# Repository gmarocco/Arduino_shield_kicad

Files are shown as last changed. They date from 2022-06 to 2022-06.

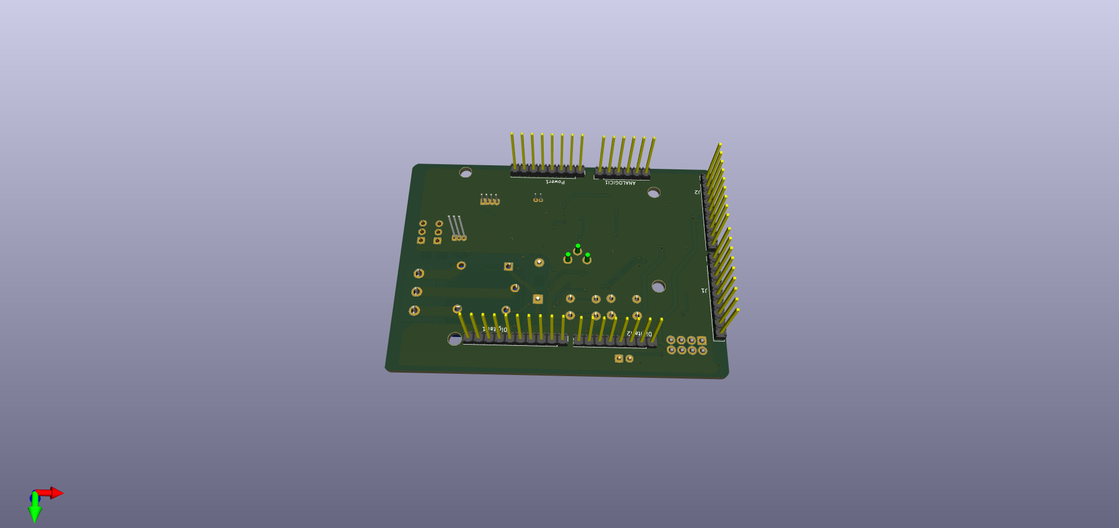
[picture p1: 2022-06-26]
documentazione Shield Arduino v2/Shield Arduino v2-1_bottom.png

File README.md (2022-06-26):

# Arduino_shield_kicad
Shield general purpose for Arduino Uno board
La scheda ospita queste sezioni
• E’ presente uno stadio che implementa un interruttore audio
• La scheda contiene un trimmer collegato a un pin analogico della scheda Arduino
• Sono presenti due pulsanti
• La scheda contiene un LED RGB da 5mm
• E’ presente un relè da 10 A
• La scheda è predisposta per ospitare il modulo Wi-Fi ESP8266
• E’ presente un regolatore lineare che genera una tensione di 3.3V con una corrente massima di 1 A
• Sono presenti due header maschio che permettono allo shield di essere collegato a una breadboard

I file di progetto sono stati realizzati con Kicad v6

English description

The board has these sections
• There is a stage that implements an audio switch
• The board contains a trimmer connected to an analog pin of the Arduino board
• There are two buttons
• The board contains a 5mm RGB LED
• There is a 10 A relay
• The card is designed to house the ESP8266 Wi-Fi module
• There is a linear regulator that generates a voltage of 3.3V with a maximum current of 1 A
• There are two male headers that allow the shield to be connected to a breadboard

The project files are made with Kicad v6

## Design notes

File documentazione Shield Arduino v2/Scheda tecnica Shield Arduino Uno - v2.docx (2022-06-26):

Documentazione Shield Arduino Uno v2

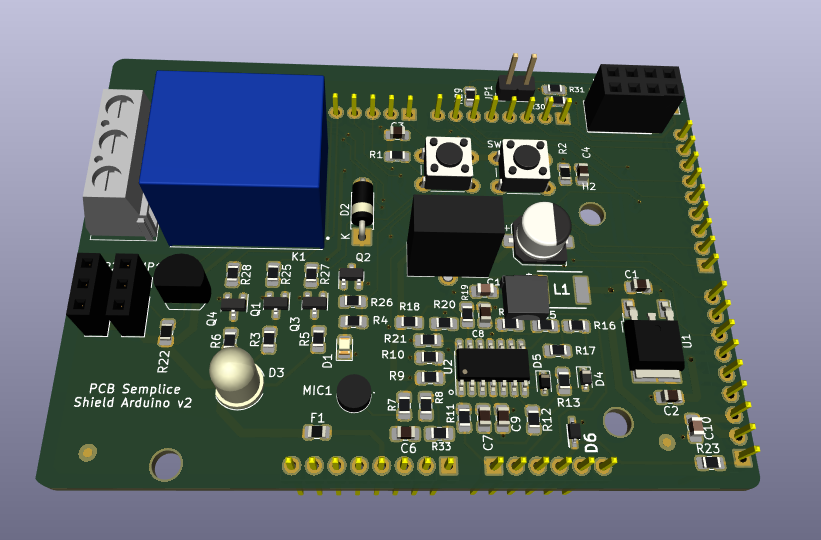
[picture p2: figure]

## Descrizione generale

La scheda ospita queste sezioni

- E’ presente uno stadio che implementa un interruttore audio
- La scheda contiene un trimmer collegato a un pin analogico della scheda Arduino
- Sono presenti due pulsanti
- La scheda contiene un LED RGB da 5mm
- E’ presente un relè da 10 A
- La scheda è predisposta per ospitare il modulo Wi-Fi ESP8266
- E’ presente un regolatore lineare che genera una tensione di 3.3V con una corrente massima di 1 A
- Sono presenti due header maschio che permettono allo shield di essere collegato a una breadboard

## Interruttore audio

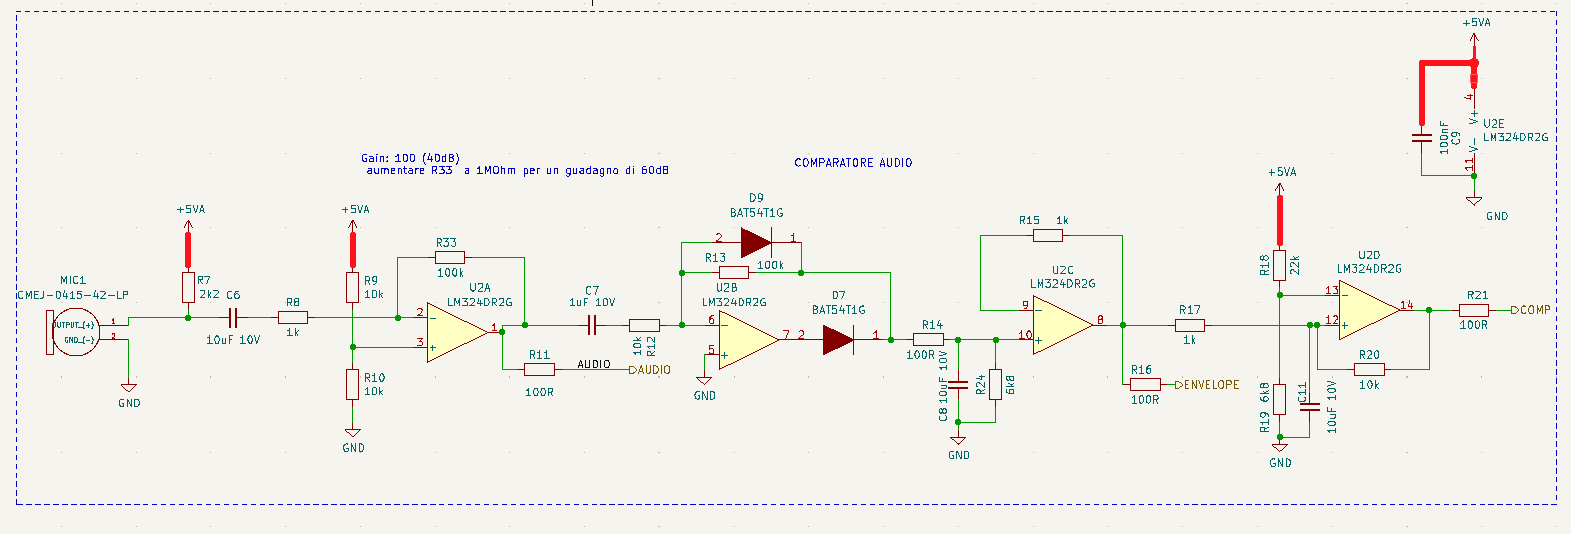
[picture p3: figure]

Lo stadio si basa sull’amplificatore operazionale a 4 canali LM324

La prima sezione (U2A) dell’operazionale realizza un amplificatore invertente. Il segnale del microfono viene amplificato e il guadagno è determinato sostanzialmente dal resistore R33

L’uscita viene inviata sia a un canale analogico della scheda Arduino Uno, sia al secondo stadio (U2B) che realizza un raddrizzatore a singola semionda (half wave rectifier).

L‘uscita del raddrizzatore viene inviata al terzo stadio (U2C) che costituisce un buffer con un filtro passa-basso.

L’uscita di quest’ultimo stadio viene inviata sia a un pin analogico della scheda Arduino Uno, sia al quarto stadio (U2D) che è un trigger di Schmitt. L’uscita (COMP) di quest’ ultimo stadio viene inviata a un pin digitale della Arduino Uno.

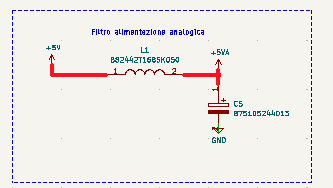
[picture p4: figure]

Per evitare commutazioni spurie, la tensione di alimentazione (+5VA) dell’operazionale è ottenuta dalla tensione +5V attraverso un filtro costituito dall’induttore L1 e dal condensatore C5

Lo sketch caricato nel microcontrollore AtMEGA328P della scheda Arduino Uno, attiva un relè quando viene pronunciato per due volte il suono “a”. Il relè viene disattivato quando viene pronunciato tre volte il suono “a”

const byte ledPin = 12;

const byte rele = 4;

const byte interruptPin = 2;

volatile byte state = LOW;

unsigned char count =0;

unsigned char ON =0;

unsigned char OFF =0;

unsigned long timeComparison = 0;

unsigned char alreadyON =0;

void setup() {

pinMode(ledPin, OUTPUT);

pinMode(interruptPin, INPUT_PULLUP);

attachInterrupt(digitalPinToInterrupt(interruptPin), checkComparator, RISING);

Serial.begin(9600);

}

void loop() {

Serial.println(count);

if (ON==1 && alreadyON==0)

{

digitalWrite(ledPin, HIGH);

digitalWrite(rele, HIGH);

alreadyON=1;

count=0;

Serial.println("ON");

}

if (OFF==1){

digitalWrite(ledPin, LOW);

digitalWrite(rele, LOW);

Serial.println("OFF");

alreadyON =0;

count=0;

OFF=0;

}

}

void checkComparator() {

count++;

switch (count){

case 1:

timeComparison=millis();

break;

case 2:

timeComparison=(millis())-timeComparison;

if (timeComparison <2000)

{

ON=1;

OFF=0;

timeComparison=millis();

}

else{

count=0;

}

break;

case 3:

timeComparison=(millis())-timeComparison;

if (timeComparison <2000)

{

ON=0;

OFF=1;

count =0;

}

else{

count=0;

}

break;

default:

count=0;

break;

}

}

## Predisposizione per collegare un modulo ESP8266

E’ possibile interfacciarsi con un modulo Wi-Fi ESP8266 montando il componente in corrispondenza del connettore J4. Orientare il modulo in modo che sia tutto all’interno dello shield.

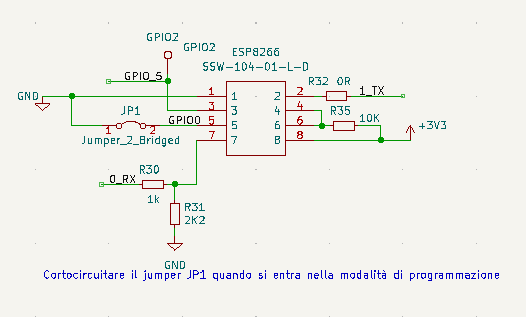
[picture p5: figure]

Prima di programmare il modulo, caricare lo sketch qui sotto nel microcontrollore ATMEGA328P della scheda Arduino Uno in modo che non si creino conflitti a livello di comunicazione seriale (pin 0 e pin 1 della scheda Arduino UNO) Lo sketch permette, inoltre di comandare il relè in base allo stato del pin GIPO5.

const int EspOutput = 5; // ESP8266 output

const int rele = 4; // the number of the LED pin

const int led= 13;

void setup() {

pinMode(EspOutput, INPUT);

pinMode(rele, OUTPUT);

pinMode(led, OUTPUT);

// put your setup code here, to run once:

}

void loop() {

if (digitalRead(EspOutput))

{

delay(500);

if (digitalRead(EspOutput))

{

digitalWrite(rele,HIGH);

digitalWrite(led,HIGH);

}

else

{

digitalWrite(led,LOW);

digitalWrite(rele,LOW);

}

}

}

La resistenza R29 permette di selezionare se collegare un’uscita digitale del modulo al pin GPIO5 della scheda Arduino Uno. In questo caso il pin della scheda Arduino dovrà essere configurato come ingresso.

Per l’impostazione del modulo, fare riferimento al video ( E’ in inglese) https://www.youtube.com/watch?v=AvSCAxbqvvE.

Prima di programmare il modulo Wi-Fi, togliere alimentazione allo shield e inserire un jumper in corrispondenza del connettore JP1. A questo punto fornire nuovamente l’alimentazione e programmare il microcontrollore usando lo sketch “Blynk_NodeMCU_ESP8266” selezionando come board “Generic ESP8266 module”. E’ fondamentale sostituire i parametri BLYNK_TEMPLATE_ID e BLYNK_DEVICE_NAME con i valori forniti quando si crea l’applicazione attraverso il portale https://blynk.cloud/

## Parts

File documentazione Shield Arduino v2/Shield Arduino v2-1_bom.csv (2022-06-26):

Source: | C:\Users\pc\Documents\progetto PCB semplice\3° versione Kicad\live\Shield Arduino v2-1\Shield Arduino v2-1.kicad_sch
Date: | 26/06/2022 13:20:24
Tool: | Eeschema (6.0.6)
Generator: | C:\Program Files\KiCad\6.0\bin\scripting\plugins/bom_csv_grouped_by_value.py
Component Count: | 84
Individual Components:
Item | Qty | Reference(s) | Value | LibPart | Footprint | Datasheet | Description | Height | MANUFACTURER | Manufacturer_Name | Manufacturer_Part_Number | Mouser Part Number | Mouser Price/Stock | STANDARD
 |  | ANALOGICI1 | Conn_01x06 | Connector_Generic:Conn_01x06 | Connector_PinHeader_2.54mm:PinHeader_1x06_P2.54mm_Vertical | ~
 |  | C1 | 10uF 10V | Device:C_Small | Capacitor_SMD:C_0805_2012Metric_Pad1.15x1.40mm_HandSolder | ~
 |  | C2 | 10uF 10V | Device:C_Small | Capacitor_SMD:C_0805_2012Metric_Pad1.15x1.40mm_HandSolder | ~
 |  | C3 | 100nF | Device:C_Small | Capacitor_SMD:C_0805_2012Metric_Pad1.15x1.40mm_HandSolder | ~
 |  | C4 | 100nF | Device:C_Small | Capacitor_SMD:C_0805_2012Metric_Pad1.15x1.40mm_HandSolder | ~
 |  | C5 | 865080253012 470uF 10V | SamacSys_lib:875105244013 | Capacitor_SMD:CP_Elec_8x6.2 | https://www.we-online.com/catalog/datasheet/875105244013.pdf | Wurth Elektronik 470uF Polymer Capacitor 10V dc Surface Mount -865080253012 | 5.8 |  | Wurth Elektronik | 875105244013 | 710-875105244013 | https://www.mouser.co.uk/ProductDetail/Wurth-Elektronik/875105244013?qs=0KOYDY2FL29vol3nJUb9dw%3D%3D
 |  | C6 | 10uF 10V | Device:C_Small | Capacitor_SMD:C_0805_2012Metric_Pad1.15x1.40mm_HandSolder | ~
 |  | C7 | 1uF 10V | Device:C_Small | Capacitor_SMD:C_0805_2012Metric_Pad1.15x1.40mm_HandSolder | ~
 |  | C8 | 10uF 10V | Device:C_Small | Capacitor_SMD:C_0805_2012Metric_Pad1.15x1.40mm_HandSolder | ~
 |  | C9 | 100nF | Device:C_Small | Capacitor_SMD:C_0805_2012Metric_Pad1.15x1.40mm_HandSolder | ~
 |  | C10 | 100nF | Device:C_Small | Capacitor_SMD:C_0805_2012Metric_Pad1.18x1.45mm_HandSolder | ~
 |  | C11 | 10uF 10V | Device:C_Small | Capacitor_SMD:C_0805_2012Metric_Pad1.18x1.45mm_HandSolder | ~
 |  | D1 | LED | Device:LED | LED_SMD:LED_0805_2012Metric | ~
 |  | D2 | 1N4001 | Diode:1N4001 | Diode_THT:D_DO-41_SOD81_P10.16mm_Horizontal | http://www.vishay.com/docs/88503/1n4001.pdf
 |  | D3 | LED_ABRG | Device:LED_ABRG | LED_THT:LED_D5.0mm-4_RGB | ~
 |  | D6 | AQ3530-01FTG | SamacSys_lib:AQ3530-01FTG | SOD2613X100N | https://www.littelfuse.com/~/media/electronics/datasheets/tvs_diode_arrays/littelfuse_tvs_diode_array_aq3530-01ftg_datasheet.pdf.pdf | 0.3pF 22kV unidirectional TVS diode | 1 |  | LITTELFUSE | AQ3530-01FTG | 576-AQ3530-01FTG | https://www.mouser.co.uk/ProductDetail/Littelfuse/AQ3530-01FTG?qs=yqaQSyyJnNi2YblDWyDyIw%3D%3D
 |  | D7 | BAT54T1G | LIBRARY LOADER_AUTO:BAT54T1G | SOD3716X135N | http://www.onsemi.com/pub/Collateral/BAT54T1-D.PDF |  | 1.35 |  | onsemi | BAT54T1G | 863-BAT54T1G | https://www.mouser.co.uk/ProductDetail/onsemi/BAT54T1G?qs=vLkC5FC1VN9XK%252B%252BtdP3lYw%3D%3D
 |  | D9 | BAT54T1G | LIBRARY LOADER_AUTO:BAT54T1G | SOD3716X135N | http://www.onsemi.com/pub/Collateral/BAT54T1-D.PDF |  | 1.35 |  | onsemi | BAT54T1G | 863-BAT54T1G | https://www.mouser.co.uk/ProductDetail/onsemi/BAT54T1G?qs=vLkC5FC1VN9XK%252B%252BtdP3lYw%3D%3D
 |  | Digitali1 | Conn_01x10 | Connector_Generic:Conn_01x10 | Connector_PinHeader_2.54mm:PinHeader_1x10_P2.54mm_Vertical | ~
 |  | Digitali2 | Conn_01x08 | Connector_Generic:Conn_01x08 | Connector_PinHeader_2.54mm:PinHeader_1x08_P2.54mm_Vertical | ~
 |  | ESP8266 | SSW-104-01-L-D | SamacSys_Parts:SSW-104-01-L-D | RHDR8W79P254_2X4_1067X495X851P | http://suddendocs.samtec.com/prints/ssw-1xx-xx-xxx-x-xx-xxx-xx-mkt.pdf | 8 Position, .100&quot; Tiger Buy&trade; Socket Strip | 8.51 |  | SAMTEC | SSW-104-01-L-D | 200-SSW10401LD | https://www.mouser.co.uk/ProductDetail/Samtec/SSW-104-01-L-D/?qs=%252BZP6%2F%252BtExtBqD4BX7Y8soA%3D%3D
 |  | F1 | 0ZCH0150FF2E | Device:Polyfuse | Fuse:Fuse_1210_3225Metric_Pad1.42x2.65mm_HandSolder | ~
 |  | FID1 | Fiducial | Mechanical:Fiducial | Fiducial:Fiducial_1mm_Mask2mm | ~
 |  | FID2 | Fiducial | Mechanical:Fiducial | Fiducial:Fiducial_1mm_Mask2mm | ~
 |  | FID3 | Fiducial | Mechanical:Fiducial | Fiducial:Fiducial_1mm_Mask2mm | ~
 |  | GPIO2 | GPIO2 | Connector:TestPoint | TestPoint:TestPoint_Pad_1.5x1.5mm | ~
 |  | H1 | MountingHole | Mechanical:MountingHole | MountingHole:MountingHole_3.2mm_M3 | ~
 |  | H2 | MountingHole | Mechanical:MountingHole | MountingHole:MountingHole_3.2mm_M3 | ~
 |  | H3 | MountingHole | Mechanical:MountingHole | MountingHole:MountingHole_3.2mm_M3 | ~
 |  | H4 | MountingHole | Mechanical:MountingHole | MountingHole:MountingHole_3.2mm_M3 | ~
 |  | J1 | Conn_01x09 | Connector_Generic:Conn_01x09 | Connector_PinHeader_2.54mm:PinHeader_1x09_P2.54mm_Vertical | ~
 |  | J2 | Conn_01x09 | Connector_Generic:Conn_01x09 | Connector_PinHeader_2.54mm:PinHeader_1x09_P2.54mm_Vertical | ~
 |  | J3 | TERMINAL BLOCK 3 POSIZIONI | SamacSys_Parts:282837-3 | LibraryLoaderAuto:TB00950803BE |  | Fixed Terminal Blocks 5.08MM PCB MOUNT 3P | 10.3 |  | TE Connectivity | 282837-3 | 571-2828373 | https://www.mouser.co.uk/ProductDetail/TE-Connectivity/282837-3?qs=A%252Bip%252BNCYi6PMRxtBYEOSrQ%3D%3D
 |  | JP1 | Jumper_2_Bridged | Jumper:Jumper_2_Bridged | Connector_PinHeader_2.54mm:PinHeader_1x02_P2.54mm_Vertical | ~
 |  | K1 | SRD-05VDC-SL-C | SRD-05VDC-SL-C:SRD-05VDC-SL-C | RELAY_SRD-05VDC-SL-C |  |  |  | SONGLE RELAY |  |  |  |  | IPC-7251
 |  | L1 | B82442T1685K050 | SamacSys_lib:B82442T1685K050 | INDPM5850X530N | https://componentsearchengine.com/Datasheets/1/B82442T1685K050.pdf | SMD / SMT Inductors (Coils), L=6800uH, 5.6mm x 5.0mm [EIA 2220] | 5.3 |  | TDK | B82442T1685K050 | 871-B82442T1685K050 | http://www.mouser.com/Search/ProductDetail.aspx?qs=x3Z3Taiycdsue7u9bW7ngg%3d%3d
 |  | MIC1 | CMEJ-0415-42-LP | LibraryLoader:CMEJ-0415-42-LP | LibraryLoaderAuto:CMEJ041542LP | https://componentsearchengine.com/Datasheets/1/CMEJ-0415-42-LP.pdf | Microphones microphone, 4 mm, electret condenser, omnidirectional, Long Pin, 2 Vdc, 42 dB sensitivity | 2 |  | CUI Inc. | CMEJ-0415-42-LP | 490-CMEJ-0415-42-LP | https://www.mouser.co.uk/ProductDetail/CUI-Devices/CMEJ-0415-42-LP?qs=PzGy0jfpSMvQKgQIwTg7Mg%3D%3D
 |  | Power1 | Conn_01x08 | Connector_Generic:Conn_01x08 | Connector_PinHeader_2.54mm:PinHeader_1x08_P2.54mm_Vertical | ~
 |  | Q1 | BC848 | Transistor_BJT:BC848 | Package_TO_SOT_SMD:SOT-23 | http://www.infineon.com/dgdl/Infineon-BC847SERIES_BC848SERIES_BC849SERIES_BC850SERIES-DS-v01_01-en.pdf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
 |  | Q2 | DMN3404L | Transistor_FET:DMN3404L | Package_TO_SOT_SMD:SOT-23 | http://www.diodes.com/assets/Datasheets/ds31787.pdf
 |  | Q3 | BC848 | Transistor_BJT:BC848 | Package_TO_SOT_SMD:SOT-23 | http://www.infineon.com/dgdl/Infineon-BC847SERIES_BC848SERIES_BC849SERIES_BC850SERIES-DS-v01_01-en.pdf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
 |  | Q4 | BC848 | Transistor_BJT:BC848 | Package_TO_SOT_SMD:SOT-23 | http://www.infineon.com/dgdl/Infineon-BC847SERIES_BC848SERIES_BC849SERIES_BC850SERIES-DS-v01_01-en.pdf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
 |  | R1 | 10K | Device:R_Small | Resistor_SMD:R_0805_2012Metric_Pad1.15x1.40mm_HandSolder | ~
 |  | R2 | 10K | Device:R_Small | Resistor_SMD:R_0805_2012Metric_Pad1.15x1.40mm_HandSolder | ~
 |  | R3 | 220R | Device:R_Small | Resistor_SMD:R_0805_2012Metric_Pad1.15x1.40mm_HandSolder | ~
 |  | R4 | 1K | Device:R_Small | Resistor_SMD:R_0805_2012Metric_Pad1.15x1.40mm_HandSolder | ~
 |  | R5 | 220R | Device:R_Small | Resistor_SMD:R_0805_2012Metric_Pad1.15x1.40mm_HandSolder | ~
 |  | R6 | 220R | Device:R_Small | Resistor_SMD:R_0805_2012Metric_Pad1.15x1.40mm_HandSolder | ~
 |  | R7 | 2k2 | Device:R | Resistor_SMD:R_0805_2012Metric_Pad1.15x1.40mm_HandSolder | ~
 |  | R8 | 1k | Device:R | Resistor_SMD:R_0805_2012Metric_Pad1.15x1.40mm_HandSolder | ~
 |  | R9 | 10k | Device:R | Resistor_SMD:R_0805_2012Metric_Pad1.15x1.40mm_HandSolder | ~
 |  | R10 | 10k | Device:R | Resistor_SMD:R_0805_2012Metric_Pad1.15x1.40mm_HandSolder | ~
 |  | R11 | 100R | Device:R | Resistor_SMD:R_0805_2012Metric_Pad1.15x1.40mm_HandSolder | ~
 |  | R12 | 10k | Device:R | Resistor_SMD:R_0805_2012Metric_Pad1.15x1.40mm_HandSolder | ~
 |  | R13 | 100k | Device:R | Resistor_SMD:R_0805_2012Metric_Pad1.15x1.40mm_HandSolder | ~
 |  | R14 | 100R | Device:R | Resistor_SMD:R_0805_2012Metric_Pad1.15x1.40mm_HandSolder | ~
 |  | R15 | 1k | Device:R | Resistor_SMD:R_0805_2012Metric_Pad1.15x1.40mm_HandSolder | ~
 |  | R16 | 100R | Device:R | Resistor_SMD:R_0805_2012Metric_Pad1.15x1.40mm_HandSolder | ~
 |  | R17 | 1k | Device:R | Resistor_SMD:R_0805_2012Metric_Pad1.15x1.40mm_HandSolder | ~
 |  | R18 | 22k | Device:R | Resistor_SMD:R_0805_2012Metric_Pad1.15x1.40mm_HandSolder | ~
 |  | R19 | 6k8 | Device:R | Resistor_SMD:R_0805_2012Metric_Pad1.15x1.40mm_HandSolder | ~
 |  | R20 | 10k | Device:R | Resistor_SMD:R_0805_2012Metric_Pad1.15x1.40mm_HandSolder | ~
 |  | R21 | 100R | Device:R | Resistor_SMD:R_0805_2012Metric_Pad1.15x1.40mm_HandSolder | ~
 |  | R22 | 10k | Device:R_Small | Resistor_SMD:R_0805_2012Metric_Pad1.15x1.40mm_HandSolder | ~
 |  | R23 | 100R | Device:R_Small | Resistor_SMD:R_0805_2012Metric_Pad1.20x1.40mm_HandSolder | ~
 |  | R24 | 6k8 | Device:R | Resistor_SMD:R_0805_2012Metric_Pad1.20x1.40mm_HandSolder | ~
 |  | R26 | 3k3 | Device:R_Small | Resistor_SMD:R_0805_2012Metric_Pad1.20x1.40mm_HandSolder | ~
 |  | R27 | 1K | Device:R_Small | Resistor_SMD:R_0805_2012Metric_Pad1.20x1.40mm_HandSolder | ~
 |  | R28 | 1K | Device:R_Small | Resistor_SMD:R_0805_2012Metric_Pad1.20x1.40mm_HandSolder | ~
 |  | R29 | 0R | Device:R_Small | Resistor_SMD:R_0805_2012Metric_Pad1.20x1.40mm_HandSolder | ~
 |  | R30 | 1k | Device:R_Small | Resistor_SMD:R_0805_2012Metric_Pad1.20x1.40mm_HandSolder | ~
 |  | R31 | 2K2 | Device:R_Small | Resistor_SMD:R_0805_2012Metric_Pad1.20x1.40mm_HandSolder | ~
 |  | R32 | 0R | Device:R_Small | Resistor_SMD:R_0805_2012Metric_Pad1.20x1.40mm_HandSolder | ~
 |  | R33 | 100k | Device:R | Resistor_SMD:R_0805_2012Metric_Pad1.20x1.40mm_HandSolder | ~
 |  | R34 | 220k | Device:R_Small | Resistor_SMD:R_0805_2012Metric_Pad1.20x1.40mm_HandSolder | ~
 |  | R35 | 10K | Device:R_Small | Resistor_SMD:R_0805_2012Metric_Pad1.20x1.40mm_HandSolder | ~
 |  | SW1 | SW_Push | Switch:SW_Push | Button_Switch_THT:SW_PUSH_6mm_H4.3mm | ~
 |  | SW2 | SW_Push | Switch:SW_Push | Button_Switch_THT:SW_PUSH_6mm_H4.3mm | ~
 |  | TEMP1 | Conn_01x03 | Connector_Generic:Conn_01x03 | Connector_PinSocket_2.54mm:PinSocket_1x03_P2.54mm_Vertical | ~
 |  | TEMP2 | Conn_01x03 | Connector_Generic:Conn_01x03 | Connector_PinSocket_2.54mm:PinSocket_1x03_P2.54mm_Vertical | ~
 |  | U1 | NCP1117-3.3 | Regulator_Linear:NCP1117-3.3_TO252 | Package_TO_SOT_SMD:TO-252-2 | http://www.onsemi.com/pub_link/Collateral/NCP1117-D.PDF
 |  | U2 | LM324DR2G | Amplifier_Operational:LM324 | Package_SO:SOIC-14_3.9x8.7mm_P1.27mm | http://www.ti.com/lit/ds/symlink/lm2902-n.pdf
 |  | U3 | DS18B20 | Sensor_Temperature:DS18B20 | Package_TO_SOT_THT:TO-92_Inline | http://datasheets.maximintegrated.com/en/ds/DS18B20.pdf
 |  | VR1 | PT10MH01-103A2020-S | SamacSys_lib:PT10MH01-103A2020-S | LibraryLoaderAuto:PT10MH01103A2020S | https://www.piher.net/pdf/12-PT10v03.pdf | TRIMMER, 10K, 0.15W, 1TURN; Track Resistance:10kohm; No. of Turns:1Turns; Potentiometer Mounting:Through Hole; Product Range:PT-10 Series; Power Rating:150mW; Resistance Tolerance:+/- 20%; Temperature Coefficient:+/- 300ppm/C; RoHS Compliant: Yes | 12.3 |  | PIHER | PT10MH01-103A2020-S | 531-PT10MH-10K-S | https://www.mouser.co.uk/ProductDetail/Amphenol-Piher/PT10MH01-103A2020-S?qs=pCZPOPZMYPhUHYDrMqsu3w%3D%3D
Collated Components:
Item | Qty | Reference(s) | Value | LibPart | Footprint | Datasheet | Description | Height | MANUFACTURER | Manufacturer_Name | Manufacturer_Part_Number | Mouser Part Number | Mouser Price/Stock | STANDARD
1 | 1 | ANALOGICI1 | Conn_01x06 | Connector_Generic:Conn_01x06 | Connector_PinHeader_2.54mm:PinHeader_1x06_P2.54mm_Vertical | ~
2 | 4 | C1, C2, C6, C8 | 10uF 10V | Device:C_Small | Capacitor_SMD:C_0805_2012Metric_Pad1.15x1.40mm_HandSolder | ~
3 | 3 | C3, C4, C9 | 100nF | Device:C_Small | Capacitor_SMD:C_0805_2012Metric_Pad1.15x1.40mm_HandSolder | ~
4 | 1 | C5 | 865080253012 470uF 10V | SamacSys_lib:875105244013 | Capacitor_SMD:CP_Elec_8x6.2 | https://www.we-online.com/catalog/datasheet/875105244013.pdf | Wurth Elektronik 470uF Polymer Capacitor 10V dc Surface Mount -865080253012 | 5.8 |  | Wurth Elektronik | 875105244013 | 710-875105244013 | https://www.mouser.co.uk/ProductDetail/Wurth-Elektronik/875105244013?qs=0KOYDY2FL29vol3nJUb9dw%3D%3D
5 | 1 | C7 | 1uF 10V | Device:C_Small | Capacitor_SMD:C_0805_2012Metric_Pad1.15x1.40mm_HandSolder | ~
6 | 1 | C10 | 100nF | Device:C_Small | Capacitor_SMD:C_0805_2012Metric_Pad1.18x1.45mm_HandSolder | ~
7 | 1 | C11 | 10uF 10V | Device:C_Small | Capacitor_SMD:C_0805_2012Metric_Pad1.18x1.45mm_HandSolder | ~
8 | 1 | D1 | LED | Device:LED | LED_SMD:LED_0805_2012Metric | ~
9 | 1 | D2 | 1N4001 | Diode:1N4001 | Diode_THT:D_DO-41_SOD81_P10.16mm_Horizontal | http://www.vishay.com/docs/88503/1n4001.pdf
10 | 1 | D3 | LED_ABRG | Device:LED_ABRG | LED_THT:LED_D5.0mm-4_RGB | ~
11 | 1 | D6 | AQ3530-01FTG | SamacSys_lib:AQ3530-01FTG | SOD2613X100N | https://www.littelfuse.com/~/media/electronics/datasheets/tvs_diode_arrays/littelfuse_tvs_diode_array_aq3530-01ftg_datasheet.pdf.pdf | 0.3pF 22kV unidirectional TVS diode | 1 |  | LITTELFUSE | AQ3530-01FTG | 576-AQ3530-01FTG | https://www.mouser.co.uk/ProductDetail/Littelfuse/AQ3530-01FTG?qs=yqaQSyyJnNi2YblDWyDyIw%3D%3D
12 | 2 | D7, D9 | BAT54T1G | LIBRARY LOADER_AUTO:BAT54T1G | SOD3716X135N | http://www.onsemi.com/pub/Collateral/BAT54T1-D.PDF |  | 1.35 |  | onsemi | BAT54T1G | 863-BAT54T1G | https://www.mouser.co.uk/ProductDetail/onsemi/BAT54T1G?qs=vLkC5FC1VN9XK%252B%252BtdP3lYw%3D%3D
13 | 1 | Digitali1 | Conn_01x10 | Connector_Generic:Conn_01x10 | Connector_PinHeader_2.54mm:PinHeader_1x10_P2.54mm_Vertical | ~
14 | 2 | Digitali2, Power1 | Conn_01x08 | Connector_Generic:Conn_01x08 | Connector_PinHeader_2.54mm:PinHeader_1x08_P2.54mm_Vertical | ~
15 | 1 | ESP8266 | SSW-104-01-L-D | SamacSys_Parts:SSW-104-01-L-D | RHDR8W79P254_2X4_1067X495X851P | http://suddendocs.samtec.com/prints/ssw-1xx-xx-xxx-x-xx-xxx-xx-mkt.pdf | 8 Position, .100&quot; Tiger Buy&trade; Socket Strip | 8.51 |  | SAMTEC | SSW-104-01-L-D | 200-SSW10401LD | https://www.mouser.co.uk/ProductDetail/Samtec/SSW-104-01-L-D/?qs=%252BZP6%2F%252BtExtBqD4BX7Y8soA%3D%3D
16 | 1 | F1 | 0ZCH0150FF2E | Device:Polyfuse | Fuse:Fuse_1210_3225Metric_Pad1.42x2.65mm_HandSolder | ~
17 | 3 | FID1, FID2, FID3 | Fiducial | Mechanical:Fiducial | Fiducial:Fiducial_1mm_Mask2mm | ~
18 | 1 | GPIO2 | GPIO2 | Connector:TestPoint | TestPoint:TestPoint_Pad_1.5x1.5mm | ~
19 | 4 | H1, H2, H3, H4 | MountingHole | Mechanical:MountingHole | MountingHole:MountingHole_3.2mm_M3 | ~
20 | 2 | J1, J2 | Conn_01x09 | Connector_Generic:Conn_01x09 | Connector_PinHeader_2.54mm:PinHeader_1x09_P2.54mm_Vertical | ~
21 | 1 | J3 | TERMINAL BLOCK 3 POSIZIONI | SamacSys_Parts:282837-3 | LibraryLoaderAuto:TB00950803BE |  | Fixed Terminal Blocks 5.08MM PCB MOUNT 3P | 10.3 |  | TE Connectivity | 282837-3 | 571-2828373 | https://www.mouser.co.uk/ProductDetail/TE-Connectivity/282837-3?qs=A%252Bip%252BNCYi6PMRxtBYEOSrQ%3D%3D
22 | 1 | JP1 | Jumper_2_Bridged | Jumper:Jumper_2_Bridged | Connector_PinHeader_2.54mm:PinHeader_1x02_P2.54mm_Vertical | ~
23 | 1 | K1 | SRD-05VDC-SL-C | SRD-05VDC-SL-C:SRD-05VDC-SL-C | RELAY_SRD-05VDC-SL-C |  |  |  | SONGLE RELAY |  |  |  |  | IPC-7251
24 | 1 | L1 | B82442T1685K050 | SamacSys_lib:B82442T1685K050 | INDPM5850X530N | https://componentsearchengine.com/Datasheets/1/B82442T1685K050.pdf | SMD / SMT Inductors (Coils), L=6800uH, 5.6mm x 5.0mm [EIA 2220] | 5.3 |  | TDK | B82442T1685K050 | 871-B82442T1685K050 | http://www.mouser.com/Search/ProductDetail.aspx?qs=x3Z3Taiycdsue7u9bW7ngg%3d%3d
25 | 1 | MIC1 | CMEJ-0415-42-LP | LibraryLoader:CMEJ-0415-42-LP | LibraryLoaderAuto:CMEJ041542LP | https://componentsearchengine.com/Datasheets/1/CMEJ-0415-42-LP.pdf | Microphones microphone, 4 mm, electret condenser, omnidirectional, Long Pin, 2 Vdc, 42 dB sensitivity | 2 |  | CUI Inc. | CMEJ-0415-42-LP | 490-CMEJ-0415-42-LP | https://www.mouser.co.uk/ProductDetail/CUI-Devices/CMEJ-0415-42-LP?qs=PzGy0jfpSMvQKgQIwTg7Mg%3D%3D
26 | 3 | Q1, Q3, Q4 | BC848 | Transistor_BJT:BC848 | Package_TO_SOT_SMD:SOT-23 | http://www.infineon.com/dgdl/Infineon-BC847SERIES_BC848SERIES_BC849SERIES_BC850SERIES-DS-v01_01-en.pdf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
27 | 1 | Q2 | DMN3404L | Transistor_FET:DMN3404L | Package_TO_SOT_SMD:SOT-23 | http://www.diodes.com/assets/Datasheets/ds31787.pdf
28 | 2 | R1, R2 | 10K | Device:R_Small | Resistor_SMD:R_0805_2012Metric_Pad1.15x1.40mm_HandSolder | ~
29 | 3 | R3, R5, R6 | 220R | Device:R_Small | Resistor_SMD:R_0805_2012Metric_Pad1.15x1.40mm_HandSolder | ~
30 | 1 | R4 | 1K | Device:R_Small | Resistor_SMD:R_0805_2012Metric_Pad1.15x1.40mm_HandSolder | ~
31 | 1 | R7 | 2k2 | Device:R | Resistor_SMD:R_0805_2012Metric_Pad1.15x1.40mm_HandSolder | ~
32 | 3 | R8, R15, R17 | 1k | Device:R | Resistor_SMD:R_0805_2012Metric_Pad1.15x1.40mm_HandSolder | ~
33 | 4 | R9, R10, R12, R20 | 10k | Device:R | Resistor_SMD:R_0805_2012Metric_Pad1.15x1.40mm_HandSolder | ~
34 | 4 | R11, R14, R16, R21 | 100R | Device:R | Resistor_SMD:R_0805_2012Metric_Pad1.15x1.40mm_HandSolder | ~
35 | 1 | R13 | 100k | Device:R | Resistor_SMD:R_0805_2012Metric_Pad1.15x1.40mm_HandSolder | ~
36 | 1 | R18 | 22k | Device:R | Resistor_SMD:R_0805_2012Metric_Pad1.15x1.40mm_HandSolder | ~
37 | 1 | R19 | 6k8 | Device:R | Resistor_SMD:R_0805_2012Metric_Pad1.15x1.40mm_HandSolder | ~
38 | 1 | R22 | 10k | Device:R_Small | Resistor_SMD:R_0805_2012Metric_Pad1.15x1.40mm_HandSolder | ~
39 | 1 | R23 | 100R | Device:R_Small | Resistor_SMD:R_0805_2012Metric_Pad1.20x1.40mm_HandSolder | ~
40 | 1 | R24 | 6k8 | Device:R | Resistor_SMD:R_0805_2012Metric_Pad1.20x1.40mm_HandSolder | ~
41 | 1 | R26 | 3k3 | Device:R_Small | Resistor_SMD:R_0805_2012Metric_Pad1.20x1.40mm_HandSolder | ~
42 | 2 | R27, R28 | 1K | Device:R_Small | Resistor_SMD:R_0805_2012Metric_Pad1.20x1.40mm_HandSolder | ~
43 | 2 | R29, R32 | 0R | Device:R_Small | Resistor_SMD:R_0805_2012Metric_Pad1.20x1.40mm_HandSolder | ~
44 | 1 | R30 | 1k | Device:R_Small | Resistor_SMD:R_0805_2012Metric_Pad1.20x1.40mm_HandSolder | ~
45 | 1 | R31 | 2K2 | Device:R_Small | Resistor_SMD:R_0805_2012Metric_Pad1.20x1.40mm_HandSolder | ~
46 | 1 | R33 | 100k | Device:R | Resistor_SMD:R_0805_2012Metric_Pad1.20x1.40mm_HandSolder | ~
47 | 1 | R34 | 220k | Device:R_Small | Resistor_SMD:R_0805_2012Metric_Pad1.20x1.40mm_HandSolder | ~
48 | 1 | R35 | 10K | Device:R_Small | Resistor_SMD:R_0805_2012Metric_Pad1.20x1.40mm_HandSolder | ~
49 | 2 | SW1, SW2 | SW_Push | Switch:SW_Push | Button_Switch_THT:SW_PUSH_6mm_H4.3mm | ~
50 | 2 | TEMP1, TEMP2 | Conn_01x03 | Connector_Generic:Conn_01x03 | Connector_PinSocket_2.54mm:PinSocket_1x03_P2.54mm_Vertical | ~
51 | 1 | U1 | NCP1117-3.3 | Regulator_Linear:NCP1117-3.3_TO252 | Package_TO_SOT_SMD:TO-252-2 | http://www.onsemi.com/pub_link/Collateral/NCP1117-D.PDF
52 | 1 | U2 | LM324DR2G | Amplifier_Operational:LM324 | Package_SO:SOIC-14_3.9x8.7mm_P1.27mm | http://www.ti.com/lit/ds/symlink/lm2902-n.pdf
53 | 1 | U3 | DS18B20 | Sensor_Temperature:DS18B20 | Package_TO_SOT_THT:TO-92_Inline | http://datasheets.maximintegrated.com/en/ds/DS18B20.pdf
54 | 1 | VR1 | PT10MH01-103A2020-S | SamacSys_lib:PT10MH01-103A2020-S | LibraryLoaderAuto:PT10MH01103A2020S | https://www.piher.net/pdf/12-PT10v03.pdf | TRIMMER, 10K, 0.15W, 1TURN; Track Resistance:10kohm; No. of Turns:1Turns; Potentiometer Mounting:Through Hole; Product Range:PT-10 Series; Power Rating:150mW; Resistance Tolerance:+/- 20%; Temperature Coefficient:+/- 300ppm/C; RoHS Compliant: Yes | 12.3 |  | PIHER | PT10MH01-103A2020-S | 531-PT10MH-10K-S | https://www.mouser.co.uk/ProductDetail/Amphenol-Piher/PT10MH01-103A2020-S?qs=pCZPOPZMYPhUHYDrMqsu3w%3D%3D

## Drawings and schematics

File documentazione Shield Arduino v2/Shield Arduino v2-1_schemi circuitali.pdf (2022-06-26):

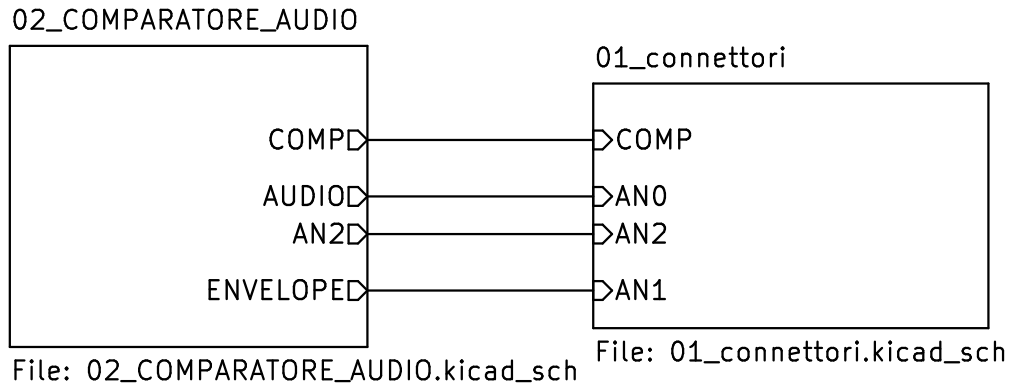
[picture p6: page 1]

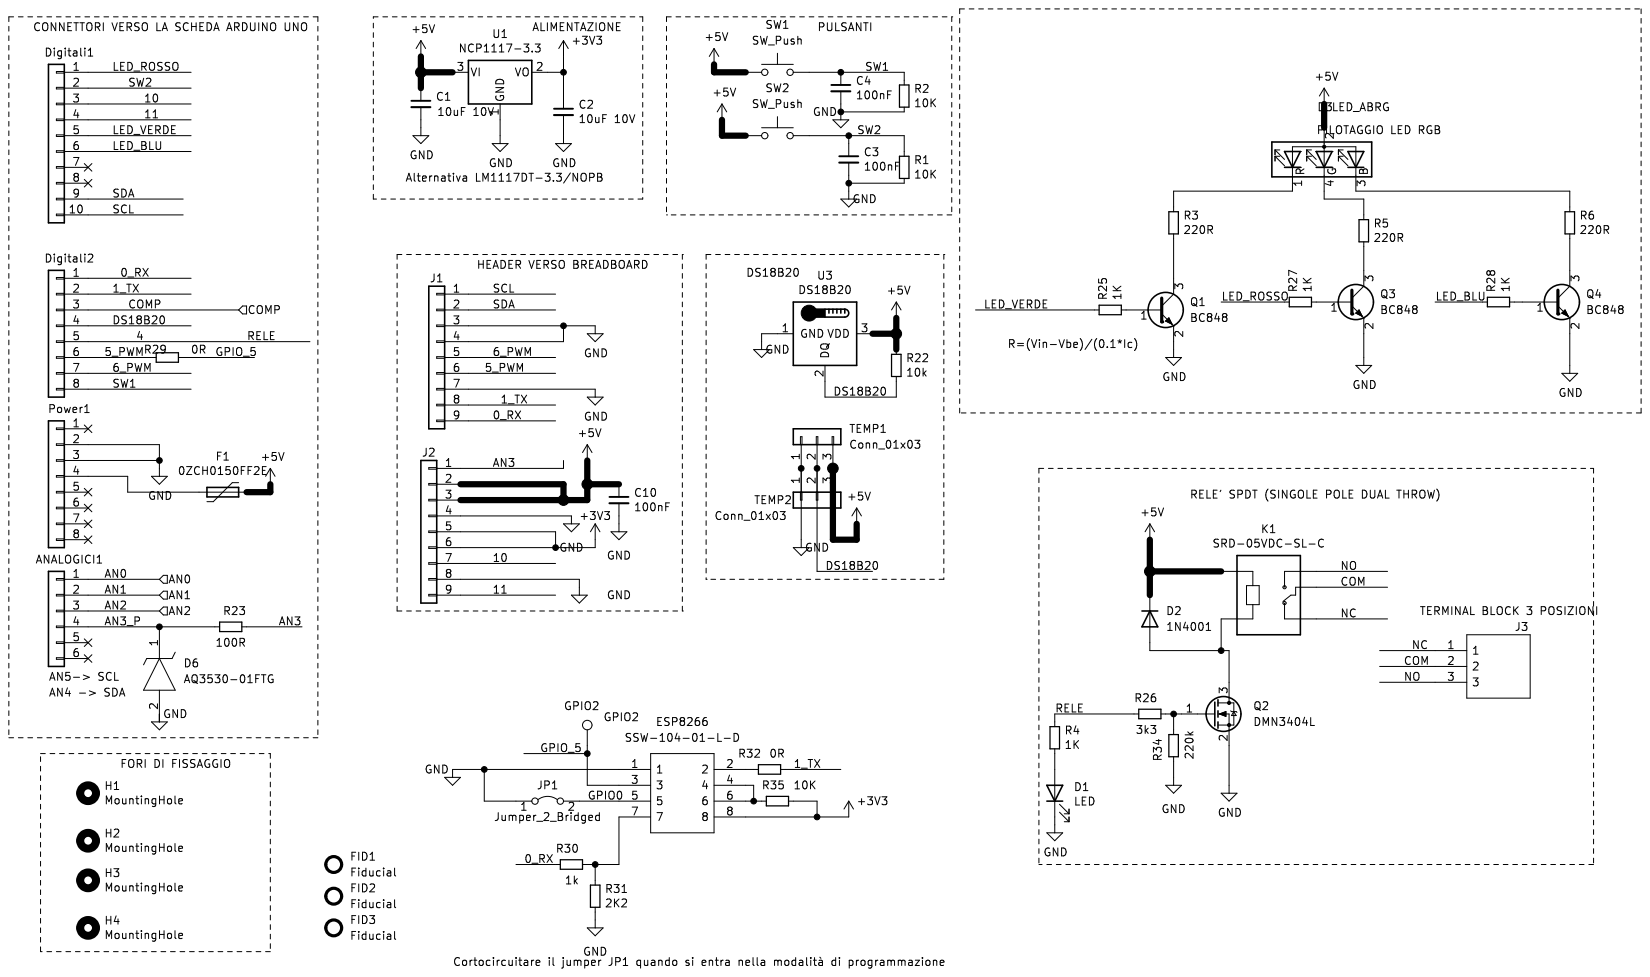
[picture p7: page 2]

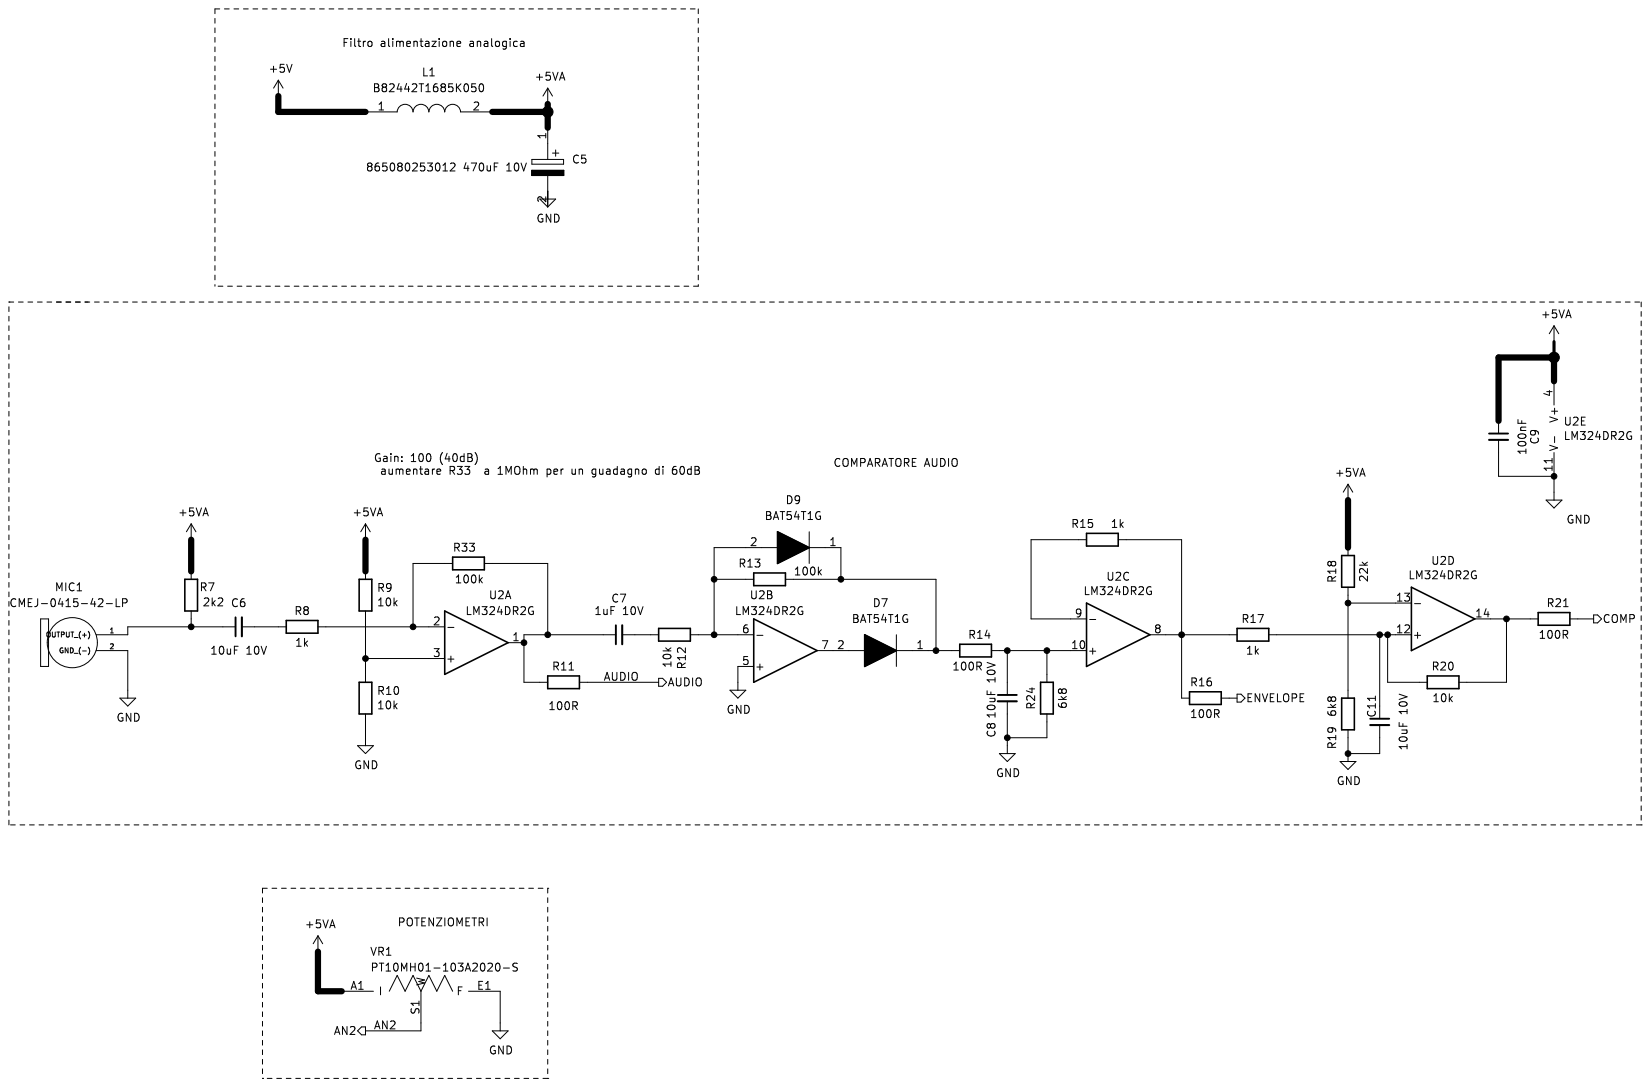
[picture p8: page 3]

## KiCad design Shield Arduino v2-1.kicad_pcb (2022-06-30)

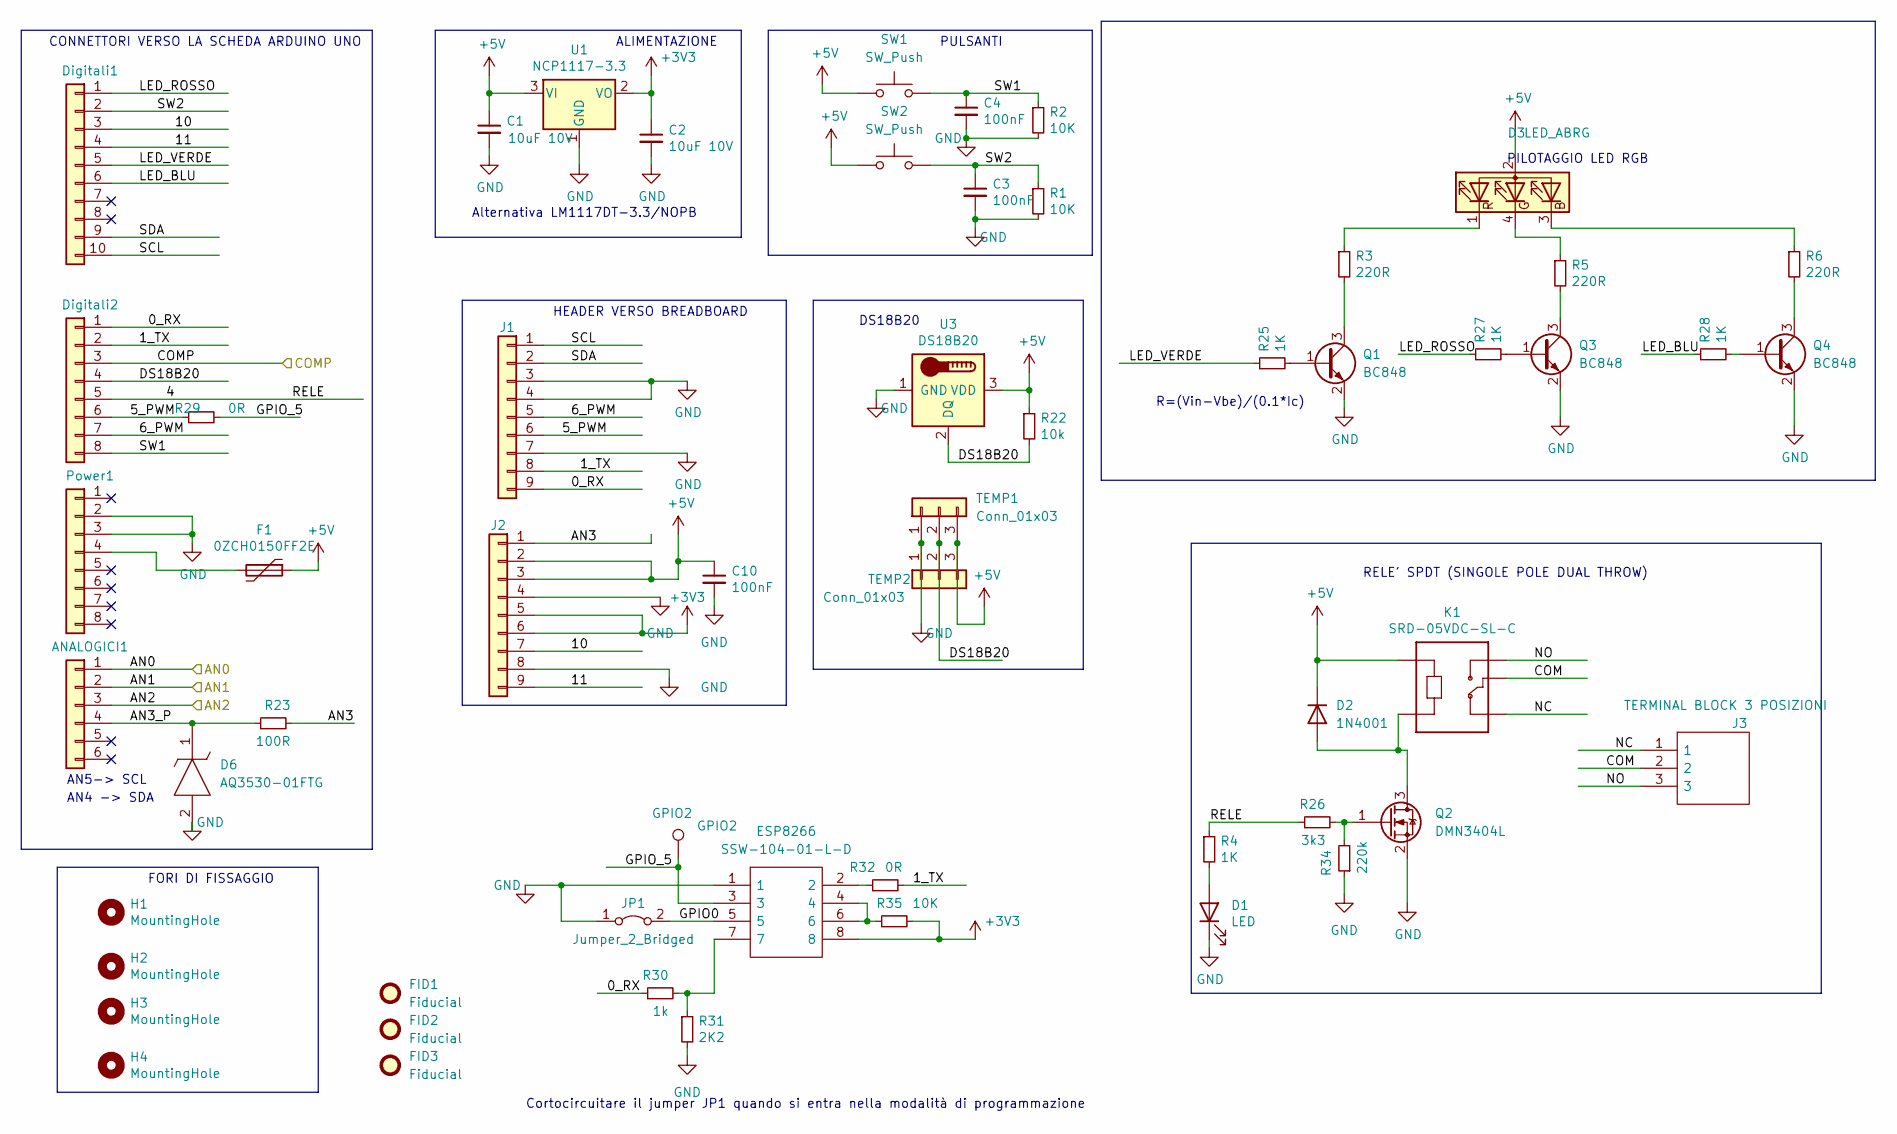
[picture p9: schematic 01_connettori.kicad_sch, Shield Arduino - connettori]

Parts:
ANALOGICI1: Conn_01x06; PinHeader_1x06_P2.54mm_Vertical
C1, C2: 10uF 10V; C_0805_2012Metric_Pad1.15x1.40mm_HandSolder
C3, C4: 100nF; C_0805_2012Metric_Pad1.15x1.40mm_HandSolder
C10: 100nF; C_0805_2012Metric_Pad1.18x1.45mm_HandSolder
D1: LED; LED_0805_2012Metric
D2: 1N4001; D_DO-41_SOD81_P10.16mm_Horizontal
D3: LED_ABRG; LED_D5.0mm-4_RGB
D6: AQ3530-01FTG; SOD2613X100N; Mouser Part Number 576-AQ3530-01FTG
Digitali1: Conn_01x10; PinHeader_1x10_P2.54mm_Vertical
Digitali2: Conn_01x08; PinHeader_1x08_P2.54mm_Vertical
ESP8266: SSW-104-01-L-D; RHDR8W79P254_2X4_1067X495X851P; Mouser Part Number 200-SSW10401LD
F1: 0ZCH0150FF2E; Fuse_1210_3225Metric_Pad1.42x2.65mm_HandSolder
FID1, FID2, FID3: Fiducial; Fiducial_1mm_Mask2mm
GPIO2: GPIO2; TestPoint_Pad_1.5x1.5mm
H1, H2, H3, H4: MountingHole; MountingHole_3.2mm_M3
J1, J2: Conn_01x09; PinHeader_1x09_P2.54mm_Vertical
J3: TERMINAL BLOCK 3 POSIZIONI; TB00950803BE; Mouser Part Number 571-2828373
JP1: Jumper_2_Bridged; PinHeader_1x02_P2.54mm_Vertical
K1: SRD-05VDC-SL-C; RELAY_SRD-05VDC-SL-C
Power1: Conn_01x08; PinHeader_1x08_P2.54mm_Vertical
Q1, Q3, Q4: BC848; SOT-23
Q2: DMN3404L; SOT-23
R1, R2: 10K; R_0805_2012Metric_Pad1.15x1.40mm_HandSolder
R3, R5, R6: 220R; R_0805_2012Metric_Pad1.15x1.40mm_HandSolder
R4: 1K; R_0805_2012Metric_Pad1.15x1.40mm_HandSolder
R22: 10k; R_0805_2012Metric_Pad1.15x1.40mm_HandSolder
R23: 100R; R_0805_2012Metric_Pad1.20x1.40mm_HandSolder
R25, R27, R28: 1K; R_0805_2012Metric_Pad1.20x1.40mm_HandSolder
R26: 3k3; R_0805_2012Metric_Pad1.20x1.40mm_HandSolder
R29, R32: 0R; R_0805_2012Metric_Pad1.20x1.40mm_HandSolder
R30: 1k; R_0805_2012Metric_Pad1.20x1.40mm_HandSolder
R31: 2K2; R_0805_2012Metric_Pad1.20x1.40mm_HandSolder
R34: 220k; R_0805_2012Metric_Pad1.20x1.40mm_HandSolder
R35: 10K; R_0805_2012Metric_Pad1.20x1.40mm_HandSolder
SW1, SW2: SW_Push; SW_PUSH_6mm_H4.3mm
TEMP1, TEMP2: Conn_01x03; PinSocket_1x03_P2.54mm_Vertical
U1: NCP1117-3.3; TO-252-2
U3: DS18B20; TO-92_Inline

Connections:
+3V3: C2.1, ESP8266.8, J2.5, J2.6, R35.2, U1.2 (VO)
+5V: C1.1, C10.1, D2.1 (K), D3.2 (A), F1.1, J2.2, J2.3, K1.A1, R22.1, SW1.1, SW2.1, TEMP1.3, TEMP2.3, U1.3 (VI), U3.3 (VDD); also elsewhere on the board
/01_connettori/0_RX: Digitali2.1, J1.9, R30.1
/01_connettori/1_TX: Digitali2.2, J1.8, R32.2
/01_connettori/4: Digitali2.5, R4.1, R26.1
/01_connettori/5_PWM: Digitali2.6, J1.6, R29.1
/01_connettori/6_PWM: Digitali2.7, J1.5
/01_connettori/10: Digitali1.3, J2.7
/01_connettori/11: Digitali1.4, J2.9
/01_connettori/AN0: ANALOGICI1.1; also elsewhere on the board
/01_connettori/AN1: ANALOGICI1.2; also elsewhere on the board
/01_connettori/AN2: ANALOGICI1.3; also elsewhere on the board
/01_connettori/AN3: J2.1, R23.2
/01_connettori/AN3_P: ANALOGICI1.4, D6.1, R23.1
/01_connettori/COM: J3.2, K1.COM
/01_connettori/COMP: Digitali2.3; also elsewhere on the board
/01_connettori/DS18B20: Digitali2.4, R22.2, TEMP1.2, TEMP2.2, U3.2 (DQ)
/01_connettori/GPIO0: ESP8266.5, JP1.2 (B)
/01_connettori/GPIO_5: ESP8266.3, GPIO2.1, R29.2
/01_connettori/LED_BLU: Digitali1.6, R28.1
/01_connettori/LED_ROSSO: Digitali1.1, R27.1
/01_connettori/LED_VERDE: Digitali1.5, R25.1
/01_connettori/NC: J3.1, K1.NC
/01_connettori/NO: J3.3, K1.NO
/01_connettori/SCL: Digitali1.10, J1.1
/01_connettori/SDA: Digitali1.9, J1.2
/01_connettori/SW1: C4.1, Digitali2.8, R2.1, SW1.2
/01_connettori/SW2: C3.1, Digitali1.2, R1.1, SW2.2
GND: C1.2, C2.2, C3.2, C4.2, C10.2, D1.1 (K), D6.2, ESP8266.1, J1.3, J1.4, J1.7, J2.4, J2.8, JP1.1 (A), Power1.2, Power1.3, Q1.2 (E), Q2.2 (S), Q3.2 (E), Q4.2 (E), R1.2, R2.2, R31.2, R34.1, TEMP1.1, TEMP2.1, U1.1 (GND), U3.1 (GND); also elsewhere on the board
unnamed: D1.2 (A), R4.2
unnamed: D2.2 (A), K1.A2, Q2.3 (D)
unnamed: D3.1 (RK), R3.1
unnamed: D3.3 (BK), R6.1
unnamed: D3.4 (GK), R5.1
unnamed: ESP8266.2, R32.1
unnamed: ESP8266.4, ESP8266.6, R35.1
unnamed: ESP8266.7, R30.2, R31.1
unnamed: F1.2, Power1.4
unnamed: Q1.1 (B), R25.2
unnamed: Q1.3 (C), R3.2
unnamed: Q3.1 (B), R27.2
unnamed: Q3.3 (C), R5.2
unnamed: Q4.1 (B), R28.2
unnamed: Q4.3 (C), R6.2
unnamed: Q2.1 (G), R26.2, R34.2

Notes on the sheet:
DS18B20
CONNETTORI VERSO LA SCHEDA ARDUINO UNO
HEADER VERSO BREADBOARD
FORI DI FISSAGGIO
PILOTAGGIO LED RGB
PULSANTI
AN4 -> SDA
AN5-> SCL
RELE' SPDT (SINGOLE POLE DUAL THROW)
R=(Vin-Vbe)/(0.1*Ic)
Cortocircuitare il jumper JP1 quando si entra nella modalità di programmazione
ALIMENTAZIONE
Alternativa LM1117DT-3.3/NOPB

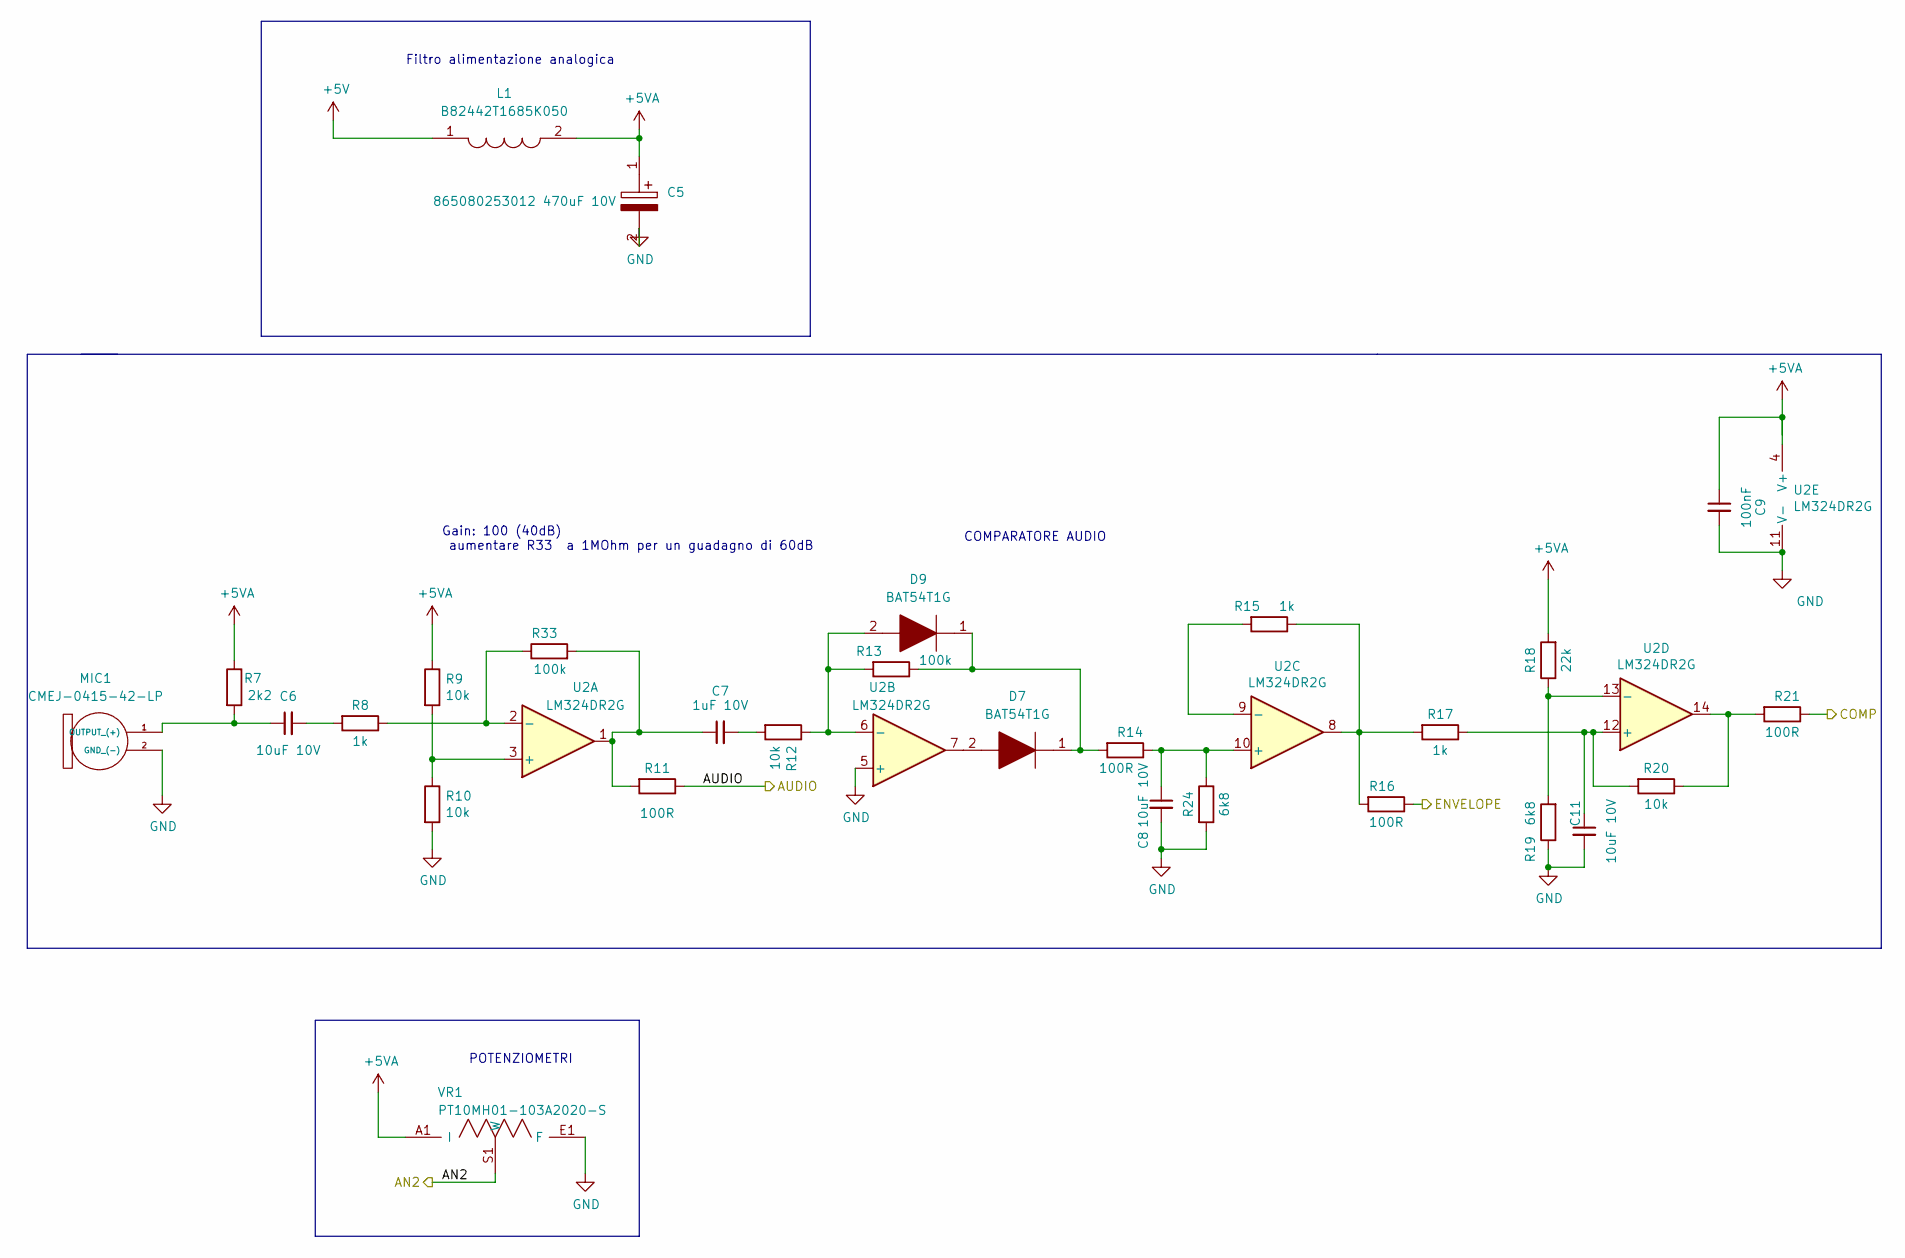
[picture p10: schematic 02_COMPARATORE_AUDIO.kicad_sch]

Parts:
C5: 865080253012 470uF 10V; CP_Elec_8x6.2; Mouser Part Number 710-875105244013
C6, C8: 10uF 10V; C_0805_2012Metric_Pad1.15x1.40mm_HandSolder
C7: 1uF 10V; C_0805_2012Metric_Pad1.15x1.40mm_HandSolder
C9: 100nF; C_0805_2012Metric_Pad1.15x1.40mm_HandSolder
C11: 10uF 10V; C_0805_2012Metric_Pad1.18x1.45mm_HandSolder
D7, D9: BAT54T1G; SOD3716X135N; Mouser Part Number 863-BAT54T1G
L1: B82442T1685K050; INDPM5850X530N; Mouser Part Number 871-B82442T1685K050
MIC1: CMEJ-0415-42-LP; CMEJ041542LP; Mouser Part Number 490-CMEJ-0415-42-LP
R7: 2k2; R_0805_2012Metric_Pad1.15x1.40mm_HandSolder
R8, R15, R17: 1k; R_0805_2012Metric_Pad1.15x1.40mm_HandSolder
R9, R10, R12, R20: 10k; R_0805_2012Metric_Pad1.15x1.40mm_HandSolder
R11, R14, R16, R21: 100R; R_0805_2012Metric_Pad1.15x1.40mm_HandSolder
R13: 100k; R_0805_2012Metric_Pad1.15x1.40mm_HandSolder
R18: 22k; R_0805_2012Metric_Pad1.15x1.40mm_HandSolder
R19: 6k8; R_0805_2012Metric_Pad1.15x1.40mm_HandSolder
R24: 6k8; R_0805_2012Metric_Pad1.20x1.40mm_HandSolder
R33: 100k; R_0805_2012Metric_Pad1.20x1.40mm_HandSolder
U2: LM324DR2G; SOIC-14_3.9x8.7mm_P1.27mm
VR1: PT10MH01-103A2020-S; PT10MH01103A2020S; Mouser Part Number 531-PT10MH-10K-S

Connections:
+5V: L1.1; also elsewhere on the board
+5VA: C5.1, C9.1, L1.2, R7.1, R9.1, R18.2, U2.4 (V+), VR1.A1 (I)
/01_connettori/AN0: R11.1; also elsewhere on the board
/01_connettori/AN1: R16.1; also elsewhere on the board
/01_connettori/AN2: VR1.S1 (W); also elsewhere on the board
/01_connettori/COMP: R21.1; also elsewhere on the board
GND: C5.2, C8.2, C9.2, C11.2, MIC1.2 (GND_(-)), R10.2, R19.1, R24.2, U2.5 (+), U2.11 (V-), VR1.E1 (F); also elsewhere on the board
unnamed: C6.1, MIC1.1 (OUTPUT_(+)), R7.2
unnamed: C6.2, R8.2
unnamed: C7.1, R11.2, R33.2, U2.1
unnamed: C7.2, R12.2
unnamed: C8.1, R14.1, R24.1, U2.10 (+)
unnamed: C11.1, R17.1, R20.2, U2.12 (+)
unnamed: R9.2, R10.1, U2.3 (+)
unnamed: D9.2, R12.1, R13.2, U2.6 (-)
unnamed: D7.1, D9.1, R13.1, R14.2
unnamed: R15.1, R16.2, R17.2, U2.8
unnamed: R15.2, U2.9 (-)
unnamed: R18.1, R19.2, U2.13 (-)
unnamed: R20.1, R21.2, U2.14
unnamed: R8.1, R33.1, U2.2 (-)
unnamed: D7.2, U2.7

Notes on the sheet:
Filtro alimentazione analogica
POTENZIOMETRI
Gain: 100 (40dB) aumentare R33 a 1MOhm per un guadagno di 60dB
COMPARATORE AUDIO

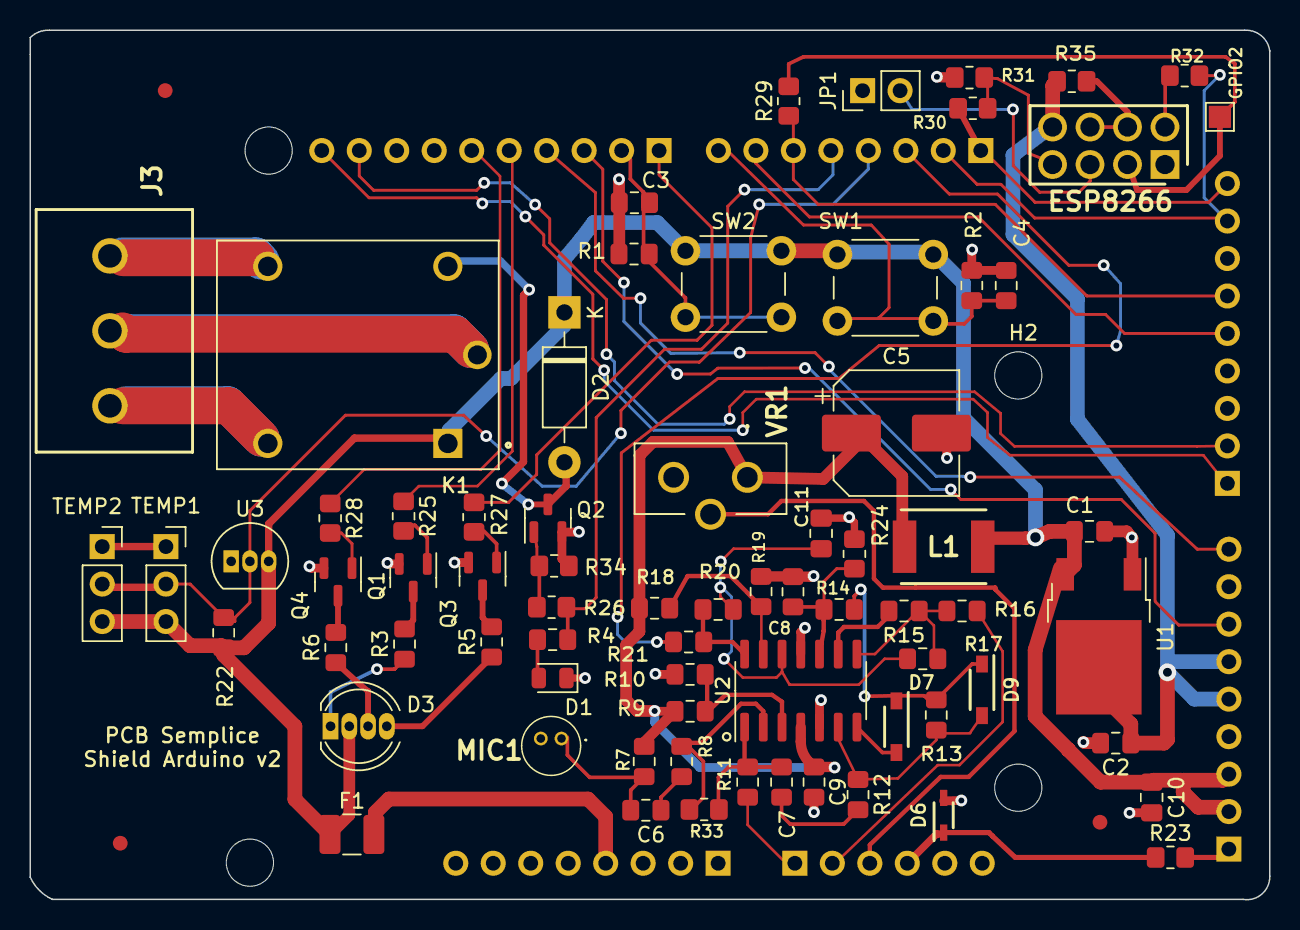
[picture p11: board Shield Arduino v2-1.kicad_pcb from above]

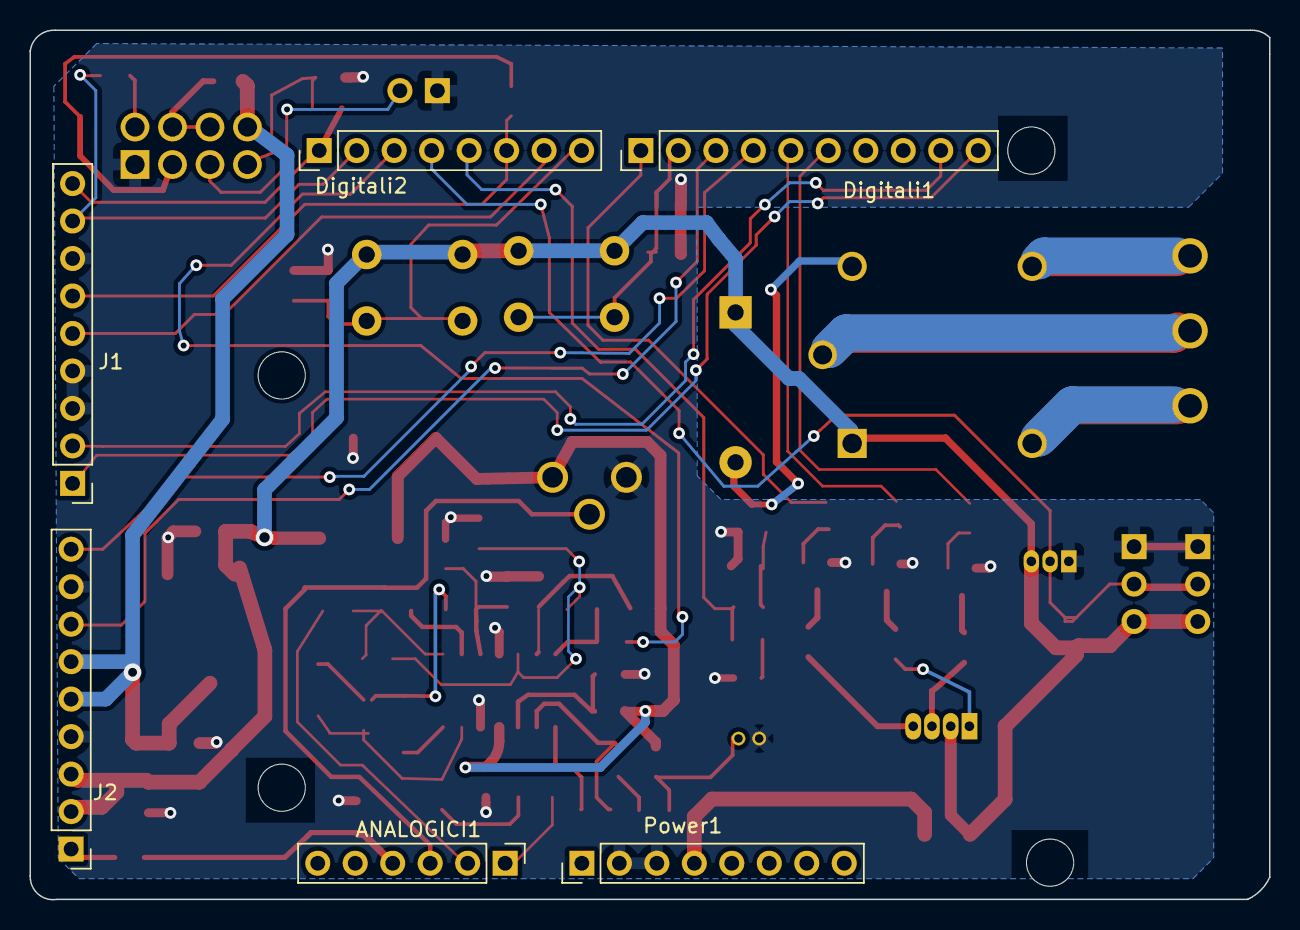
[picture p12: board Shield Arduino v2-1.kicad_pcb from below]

Board: 2 copper layers, 84.0 x 58.9 mm, 85 parts (6 on the bottom side), 61 nets.
